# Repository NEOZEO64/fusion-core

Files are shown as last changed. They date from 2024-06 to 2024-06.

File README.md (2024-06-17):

# FUSION CORE (synthesizer)

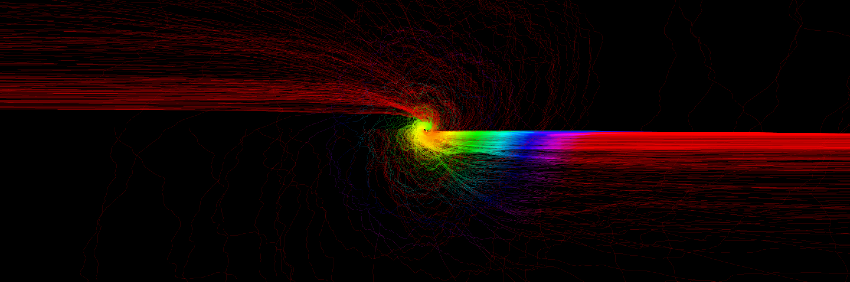
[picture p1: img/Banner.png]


## Aims

- No aim lol
- Get to know delicious circuits (experimenting a lot)
- Use them in crude ways to generate sounds
- Learn how to design circuits & professionally manufacture them with KiCad
- Learn whats possible with analog circuits and what's not
- Have a lot of fun without the need of programming

- Get an overview of electronic parts out there
- Manage a big project
- Make ambient dub techno at the end lol

## Resources
- Books
    - Make: Analog Synthesizers (from Music from outer space)
    - The Art of Electronics
    - Make: Electronics & Make: More Electronics
    - Encyclopedia of Electronic Components (Vol. 1, Vol. 2, Vol. 3)
    - Engineers Mini-Notebooks
- Internet
    - https://www.lookmumnocomputer.com/
    - https://www.eddybergman.com/
    - https://www.birthofasynth.com/Thomas_Henry/TH_main.html
    - https://musicfromouterspace.com/
    - https://www.schmitzbits.de/index.html
    - https://www.ericasynths.lv/
    - and a lot more!
- University for background theory
    - Electronics I & II
    - Signals & Systems, Control Systems
    - Communications Engineering
    - Computer Engineering

## Gallery

DIY dual 12V power supply + 5V (combined switched mode & linear regulated)


My first module! Still very early, but reliable 1V/oct frequency control and all outputs (Triangle, Saw, Rectangle) have the same voltage levels




Obviously go to Look Mum no Computer concert!

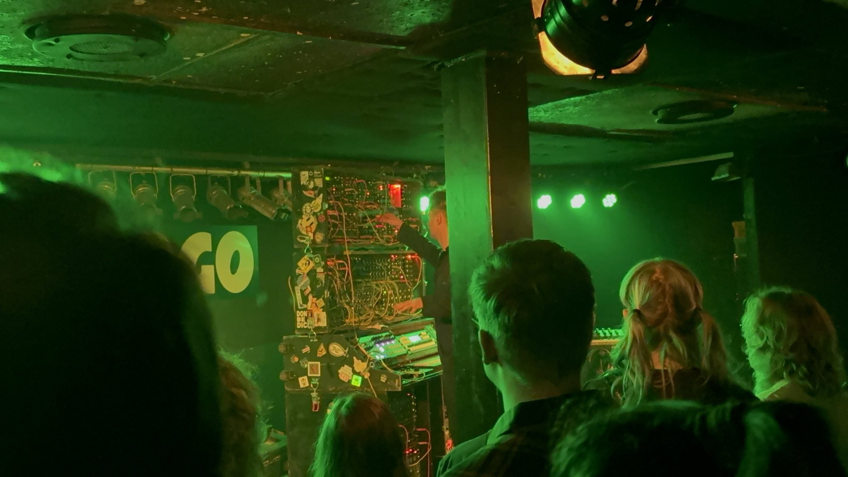
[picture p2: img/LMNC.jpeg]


Test circuits with chaotic wiring


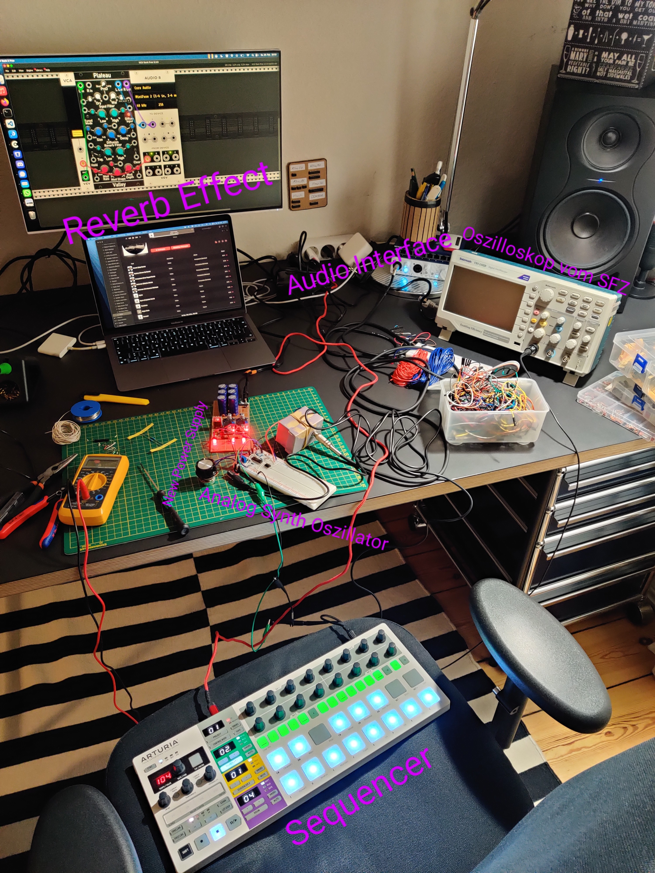
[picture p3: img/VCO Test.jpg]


Borrow devices from student research center


## Module Specifications
- ±12V, 5V Power Supply
- 16cm high, n * 2cm wide (Eurorack is too small, Cosmo too large)

- PCB-Color: Green
- Different front-plate materials (wooden, metal, PVC)

# Level 1: Basic Synth

## Chapter 1: Case
- It should be a wooden box sprayed black with fancy neon art or something

## Chapter 2: PSU
- found a better one than my own diy thing (RT65-B)

## Chapter 3: 3x VCO 
- still experimenting and learning how to design modules with input / output protection
- but first VCO tests work based on AS3340/CEM3340



Knobs:
- Big Frequency Knob
- Fine Frequency Knob
- PWM Knob

Inputs:
- PWM
- 1V/Oct
- Hard Sync
- Soft Sync

Outputs:
- Triangle
- Sawtooth
- Rectangle

## Chapter 4: 2x VCF
- First design workes based on LM13700 Operational Transconductance Amplifier, but I want to make sure it workes in every situation and the output is in voltage bounds

Knobs:
- Cutoff
- Resonance
- Drive

Inputs:
- Cutoff
- Resonance
- Drive

Output:
- Low Pass
- Band pass
- High Pass

## Chapter 5: 4x VCA

VU Meter?

Knobs:
- Volume

Inputs:
- Audio in
- CV in

Outputs:
- Audio out

## Chapter 6: 2x 4-channel Mixer
Knobs:
- Channel 1 Volume
- Channel 2 Volume
- Channel 3 Volume
- Channel 4 Volume

Inputs:
- Audio Channel 1
- Audio Channel 2
- Audio Channel 3
- Audio Channel 4

Output
- Audio Sum

## Chapter 7: Teensy 4.1 as digital signal processor for reverb / echo / distortion effects

Knobs:
- Mode
- Mod 1 (Reverb Room Size    / Echo Clock Speed)
- Mod 2 (Reverb Decay Length / Echo Feedback)

Input:
- Left Audio In
- Optional Right Audio In
- Mod 1 (Reverb Room Size    / Echo Clock Speed)

Output:
- Left Audio Out
- Right Audio Out

## Chapter 8: Audio Out (Headphones, Line Out)
- Input buffering Input / Output durch OpAmp?

- Dual Mono to Stereo
- Headphone Out
- Volume Knob
- Vu Meter

# Level 3: LMNC AAAPPPCCC Module

# Level 4: Triangle to Sine Wave Conversion

# Level 5: Beat Extension

## Chapter 1: Splitter

## Chapter 2: Clock

## Chapter 3: Clock Divider

## Chapter 4: Counter

## Chapter 5: ADSR

## Chapter 6: Manual Trigger / Gate

## Chapter 7: Sample & Hold

## Chapter 8: LFO

## Chapter 9: Constant voltage source

## Chapter 10: Signal voltage offset

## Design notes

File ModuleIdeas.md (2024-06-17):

# Analog
Oscillator (Square, Ramp, Triangle) (LFO, VCO)
Filter (High Pass, Low Pass) (Overdrive)
Amp
ADSR
Quantizer
Clock
Sequencer
Transpose
Mixer
Noise

Frequency Shift
Envelope Follower

Switch Multiplex / DEMUX
Power Supply

# With Buffer / Teensy
Echo / Delay / Flanger / Choir
Reverb
EQ
Granular
Random

Sample Machine
- Kick
- Hihat

# Arduino
Midi to VC
VC to Midi

# ?
Waveshaper

Audio Out

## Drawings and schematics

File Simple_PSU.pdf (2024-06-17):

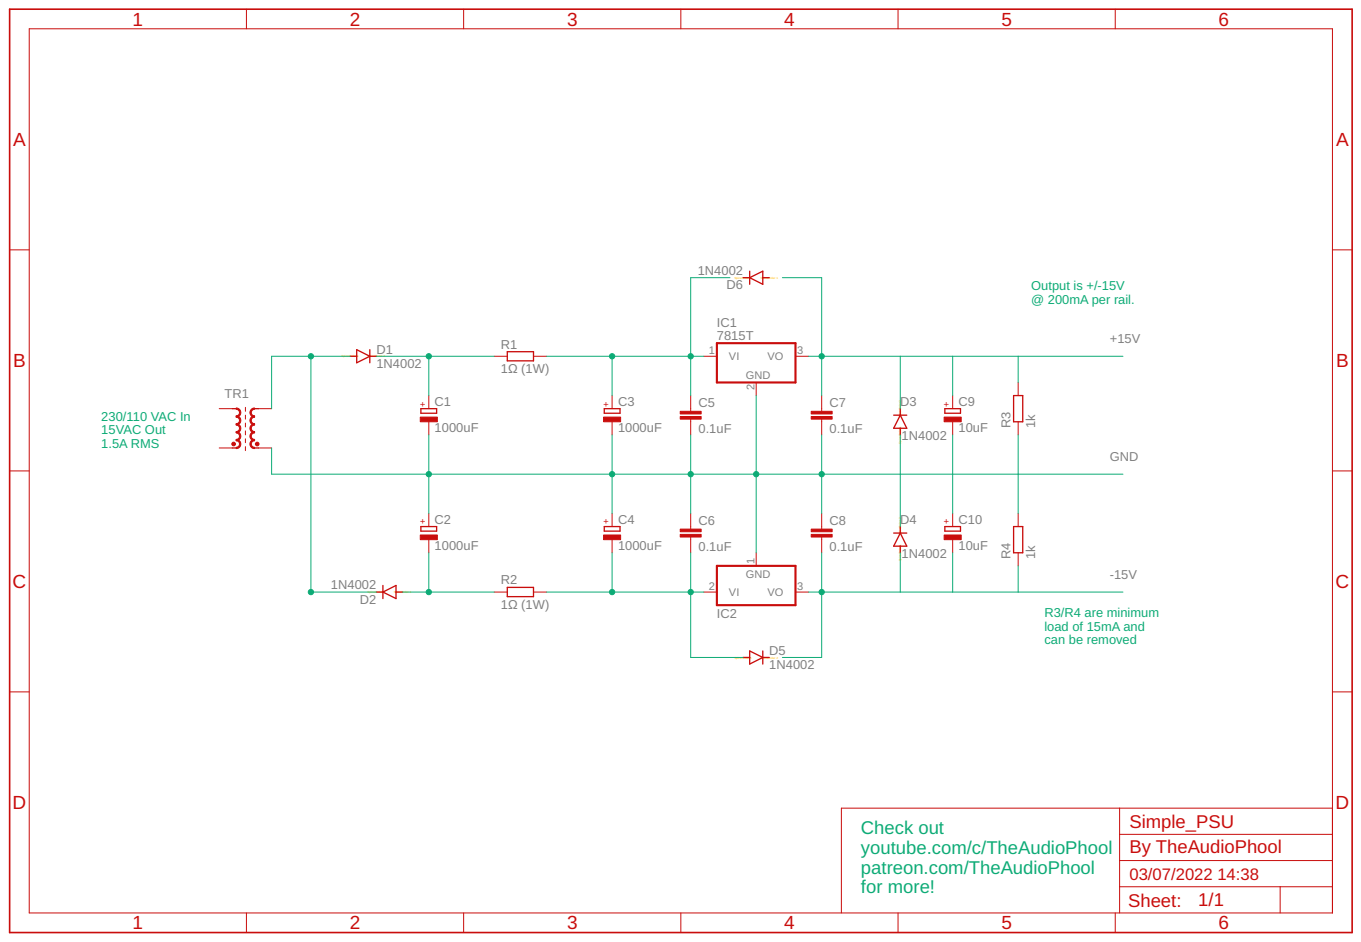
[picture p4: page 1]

SpiceOrder 1 SpiceOrder 2

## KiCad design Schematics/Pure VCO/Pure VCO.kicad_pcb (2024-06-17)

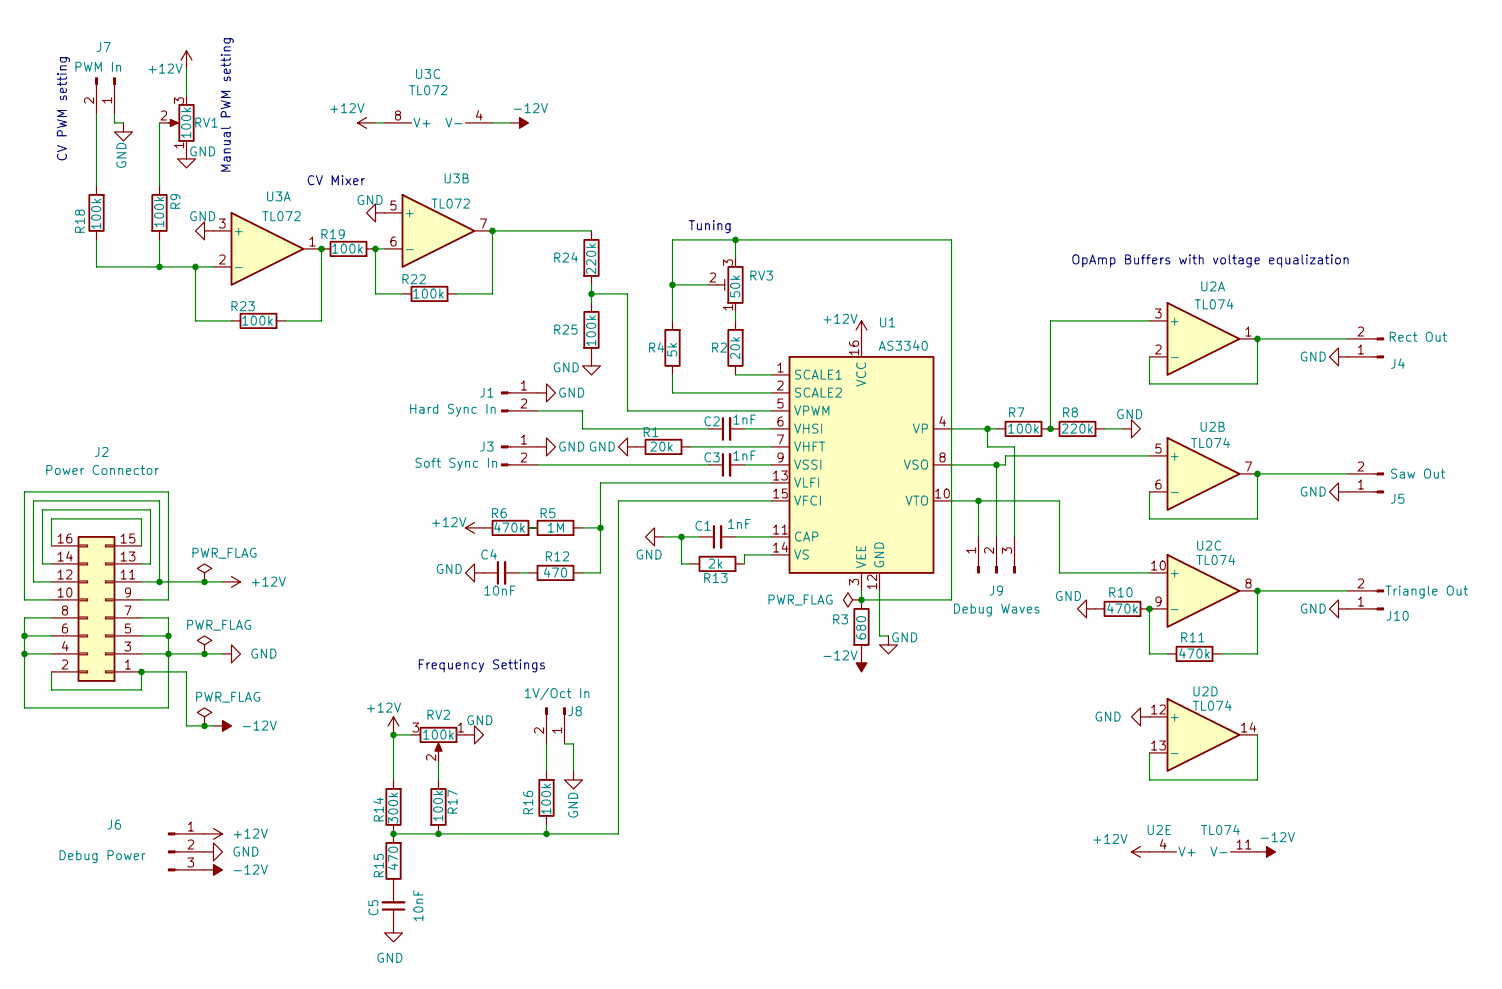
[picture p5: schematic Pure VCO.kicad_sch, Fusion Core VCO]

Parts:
C1: 1nF; C_Disc_D14.5mm_W5.0mm_P10.00mm
C2, C3: 1nF; C_Disc_D4.3mm_W1.9mm_P5.00mm
C4, C5: 10nF; C_Disc_D4.3mm_W1.9mm_P5.00mm
J1: Hard Sync In; PinHeader_1x02_P2.54mm_Vertical
J2: Power Connector; IDC-Header_2x08_P2.54mm_Vertical
J3: Soft Sync In; PinHeader_1x02_P2.54mm_Vertical
J4: Rect Out; PinHeader_1x02_P2.54mm_Vertical
J5: Saw Out; PinHeader_1x02_P2.54mm_Vertical
J6: Debug Power; PinHeader_1x03_P2.54mm_Vertical
J7: PWM In; PinHeader_1x02_P2.54mm_Vertical
J8: 1V/Oct In; PinHeader_1x02_P2.54mm_Vertical
J9: Debug Waves; PinHeader_1x03_P2.54mm_Vertical
J10: Triangle Out; PinHeader_1x02_P2.54mm_Vertical
R1, R2: 20k; R_Axial_DIN0207_L6.3mm_D2.5mm_P7.62mm_Horizontal
R3: 680; R_Axial_DIN0207_L6.3mm_D2.5mm_P7.62mm_Horizontal
R4: 5k; R_Axial_DIN0207_L6.3mm_D2.5mm_P7.62mm_Horizontal
R5: 1M; R_Axial_DIN0207_L6.3mm_D2.5mm_P7.62mm_Horizontal
R6, R10, R11: 470k; R_Axial_DIN0207_L6.3mm_D2.5mm_P7.62mm_Horizontal
R7, R9, R16, R17, R18, R19, R22, R23, R25: 100k; R_Axial_DIN0207_L6.3mm_D2.5mm_P7.62mm_Horizontal
R8, R24: 220k; R_Axial_DIN0207_L6.3mm_D2.5mm_P7.62mm_Horizontal
R12, R15: 470; R_Axial_DIN0207_L6.3mm_D2.5mm_P7.62mm_Horizontal
R13: 2k; R_Axial_DIN0207_L6.3mm_D2.5mm_P7.62mm_Horizontal
R14: 300k; R_Axial_DIN0207_L6.3mm_D2.5mm_P7.62mm_Horizontal
RV1, RV2: 100k; Potentiometer_Bourns_3386C_Horizontal
RV3: 50k; Potentiometer_Bourns_3266Y_Vertical
U1: AS3340; DIP-16_W7.62mm_Socket
U2: TL074; DIP-14_W7.62mm_Socket
U3: TL072; DIP-8_W7.62mm_Socket

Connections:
+12V: J2.11, J2.12, J6.1, R6.1, R14.2, RV1.3, RV2.3, U1.16 (VCC), U2.4 (V+), U3.8 (V+)
-12V: J2.1, J2.2, J6.3, R3.2, U2.11 (V-), U3.4 (V-)
GND: C1.1, C4.1, C5.1, J1.1, J2.3, J2.4, J2.5, J2.6, J2.7, J2.8, J3.1, J4.1, J5.1, J6.2, J7.1, J8.1, J10.1, R1.1, R8.2, R10.1, R13.1, R25.2, RV1.1, RV2.1, U1.12 (GND), U2.12 (+), U3.3 (+), U3.5 (+)
unnamed: C4.2, R12.1
unnamed: C5.2, R15.1
unnamed: C2.1, J1.2
unnamed: J2.9, J2.10
unnamed: J2.13, J2.14
unnamed: J2.15, J2.16
unnamed: C3.1, J3.2
unnamed: J4.2, U2.1, U2.2 (-)
unnamed: J5.2, U2.6 (-), U2.7
unnamed: J7.2, R18.2
unnamed: J8.2, R16.2
unnamed: J9.1, U1.10 (VTO), U2.10 (+)
unnamed: J9.2, U1.8 (VSO), U2.5 (+)
unnamed: J9.3, R7.1, U1.4 (VP)
unnamed: J10.2, R11.2, U2.8
unnamed: R2.2, RV3.1
unnamed: R5.1, R6.2
unnamed: R9.1, RV1.2
unnamed: R17.1, RV2.2
unnamed: R19.1, R23.2, U3.1
unnamed: R22.2, R24.1, U3.7
unnamed: C1.2, U1.11 (CAP)
unnamed: R2.1, U1.1 (SCALE1)
unnamed: R4.1, U1.2 (SCALE2)
unnamed: R3.1, R4.2, RV3.2, RV3.3, U1.3 (VEE)
unnamed: R14.1, R15.2, R16.1, R17.2, U1.15 (VFCI)
unnamed: R1.2, U1.7 (VHFT)
unnamed: C2.2, U1.6 (VHSI)
unnamed: R5.2, R12.2, U1.13 (VLFI)
unnamed: R24.2, R25.1, U1.5 (VPWM)
unnamed: R13.2, U1.14 (VS)
unnamed: C3.2, U1.9 (VSSI)
unnamed: R7.2, R8.1, U2.3 (+)
unnamed: R10.2, R11.1, U2.9 (-)
unnamed: U2.13 (-), U2.14
unnamed: R9.2, R18.1, R23.1, U3.2 (-)
unnamed: R19.2, R22.1, U3.6 (-)

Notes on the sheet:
Tuning
OpAmp Buffers with voltage equalization
CV PWM setting
Manual PWM setting
Frequency Settings
CV Mixer

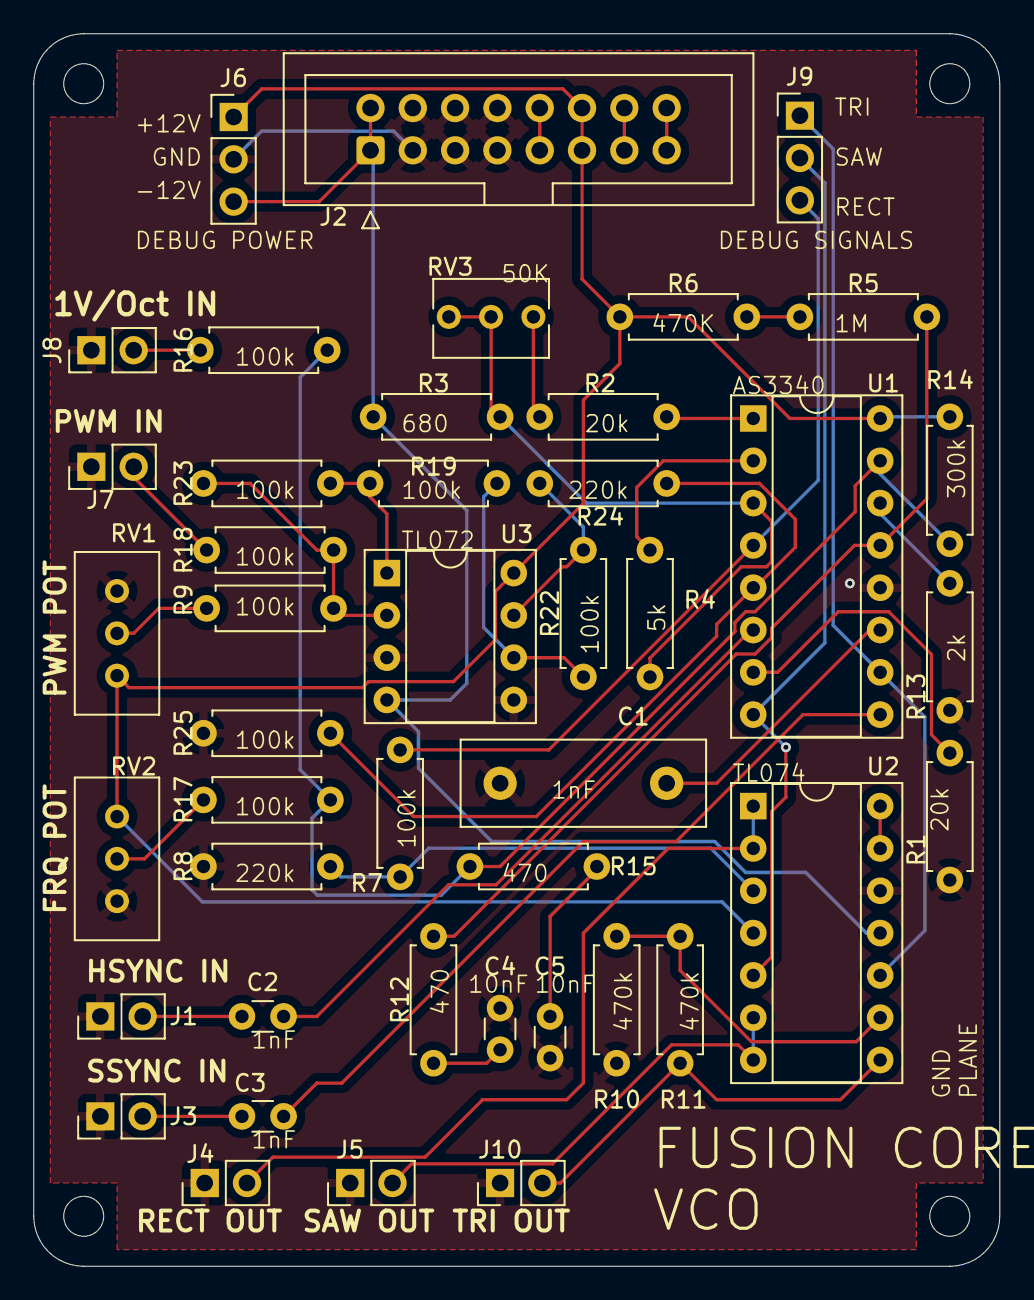
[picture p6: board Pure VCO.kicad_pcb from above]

Board: 2 copper layers, 58.0 x 74.0 mm, 44 parts (0 on the bottom side), 40 nets.

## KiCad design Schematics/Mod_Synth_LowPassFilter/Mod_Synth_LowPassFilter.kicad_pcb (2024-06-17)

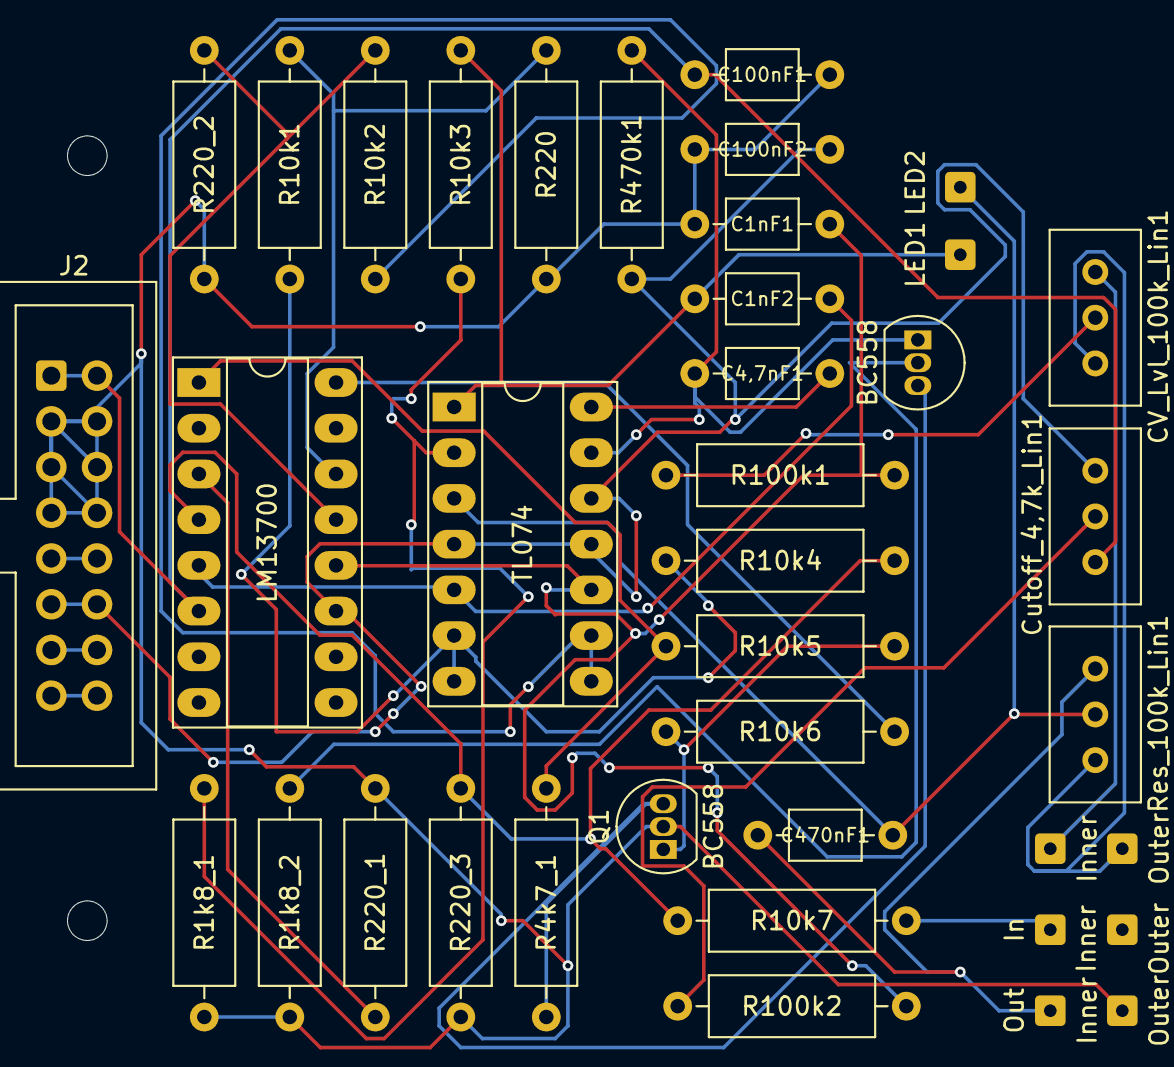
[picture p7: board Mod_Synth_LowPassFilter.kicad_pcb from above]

Board: 2 copper layers, 39 parts (0 on the bottom side), 30 nets.

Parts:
C1nF1, C1nF2, C4,7nF1, C100nF1, C100nF2, C470nF1: C; C_Axial_L3.8mm_D2.6mm_P7.50mm_Horizontal
CV_In: Inner; SolderWire-0.15sqmm_1x01_D0.5mm_OD1.5mm
CV_InputJack2: Outer; SolderWire-0.15sqmm_1x01_D0.5mm_OD1.5mm
CV_Lvl_100k_Lin1: R_Potentiometer; Potentiometer_Bourns_3386C_Horizontal
Cutoff_4,7k_Lin1: R_Potentiometer; Potentiometer_Bourns_3386C_Horizontal
In: Inner; SolderWire-0.15sqmm_1x01_D0.5mm_OD1.5mm
InputJack2: Outer; SolderWire-0.15sqmm_1x01_D0.5mm_OD1.5mm
J2: Conn_02x08_Odd_Even; IDC-Header_2x08_P2.54mm_Vertical
LEDOutput1: LED1; SolderWire-0.15sqmm_1x01_D0.5mm_OD1.5mm
LEDOutput2: LED2; SolderWire-0.15sqmm_1x01_D0.5mm_OD1.5mm
Out: Inner; SolderWire-0.15sqmm_1x01_D0.5mm_OD1.5mm
OutputJack2: Outer; SolderWire-0.15sqmm_1x01_D0.5mm_OD1.5mm
Q1, Q2: BC558; TO-92_Inline
R1k8_1, R1k8_2, R4k7_1, R10k1, R10k2, R10k3, R10k4, R10k5, R10k6, R10k7, R100k1, R100k2, R220, R220_1, R220_2, R220_3, R470k1: R; R_Axial_DIN0309_L9.0mm_D3.2mm_P12.70mm_Horizontal
Res_100k_Lin1: R_Potentiometer; Potentiometer_Bourns_3386C_Horizontal
U1: LM13700; DIP-16_W7.62mm_Socket_LongPads
U2: TL074; DIP-14_W7.62mm_Socket_LongPads

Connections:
unnamed: C4,7nF1.2, U2.14
unnamed: CV_In.1, CV_Lvl_100k_Lin1.1
unnamed: CV_InputJack2.1, CV_Lvl_100k_Lin1.3, Res_100k_Lin1.3
unnamed: CV_Lvl_100k_Lin1.2, R100k1.1
unnamed: Cutoff_4,7k_Lin1.2, R100k2.2
unnamed: In.1, R10k7.1
unnamed: C100nF1.1, Cutoff_4,7k_Lin1.3, J2.1, J2.2, U1.6 (V-)
unnamed: C1nF1.1, C100nF1.2, C100nF2.1, J2.3, J2.4, J2.5, J2.6, J2.7, J2.8, OutputJack2.1, Q1.2 (B), R1k8_1.1, R1k8_2.1, R220.1, R220_1.2, R220_2.1, R220_3.1
unnamed: J2.9, J2.10
unnamed: C100nF2.2, Cutoff_4,7k_Lin1.1, J2.11, J2.12, R470k1.1, U1.11 (V+), U2.4 (V+), U2.11 (V-), U2.12 (+)
unnamed: J2.13, J2.14
unnamed: J2.15, J2.16
unnamed: C1nF2.1, LEDOutput1.1, R10k3.2, U2.1
unnamed: C470nF1.2, LEDOutput2.1, Res_100k_Lin1.2, U2.3 (+)
unnamed: C470nF1.1, Out.1, Res_100k_Lin1.1
unnamed: Q1.1 (C), R10k5.2, R10k6.1
unnamed: Q1.3 (E), Q2.3 (E), R4k7_1.1
unnamed: Q2.2 (B), R1k8_2.2
unnamed: C4,7nF1.1, Q2.1 (C), R470k1.2, U2.13 (-)
unnamed: R4k7_1.2, R10k5.1, U1.1
unnamed: R10k6.2, U1.16
unnamed: R10k1.2, R220.2, U1.14 (+)
unnamed: R10k2.2, R220_2.2, U1.13 (-)
unnamed: R220_1.1, U1.3 (+)
unnamed: R10k4.2, R10k7.2, R220_3.2, U1.4 (-)
unnamed: R1k8_1.2, R10k3.1, U2.2 (-)
unnamed: C1nF2.2, U1.5, U2.5 (+)
unnamed: R10k1.1, R10k4.1, U2.6 (-), U2.7
unnamed: C1nF1.2, R100k1.2, R100k2.1, U1.12, U2.10 (+)
unnamed: R10k2.1, U2.8, U2.9 (-)
